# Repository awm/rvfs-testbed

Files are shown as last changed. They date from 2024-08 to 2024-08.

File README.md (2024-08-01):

# RISC-V from Scratch Testbed

This project is ancillary to the primary RISC-V from Scratch (CPU) project and is concerned with the design and
implementation of the debugging, programming, and testing infrastructure for the processor.

## Requirements

*TBD*

## Experiments

The `experiments` subdirectory contains some hardware and firmware designs explore potential features of the testbed
prior to incorporating them into the testbed architecture.  They are presented as-is and will not be updated after the
experiment is concluded.

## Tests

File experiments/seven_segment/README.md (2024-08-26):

# Hexadecimal Seven Segment Chain Experiment

## Hardware Architecture

Using shift registers, two seven-segment displays are chained so that they can all be updated via a low pin count
interface on the RP2040 (transmit-only SPI 1 port).  Each display digit requires an 8-bit shift register (7 segments and
the decimal point), conveniently fitting each into one byte.  The shift registers are linked in a cascaded manner, with
the first data input tied to the SPI 1 TX pin on the microcontroller and the shift register clock driven by the SPI
clock, with the SPI port configured in mode 0 (CPOL = 0, CPHA = 0).  Finally, shift register storage clock is driven by
the SPI chip select line, latching the latest shifted-in values to the display.

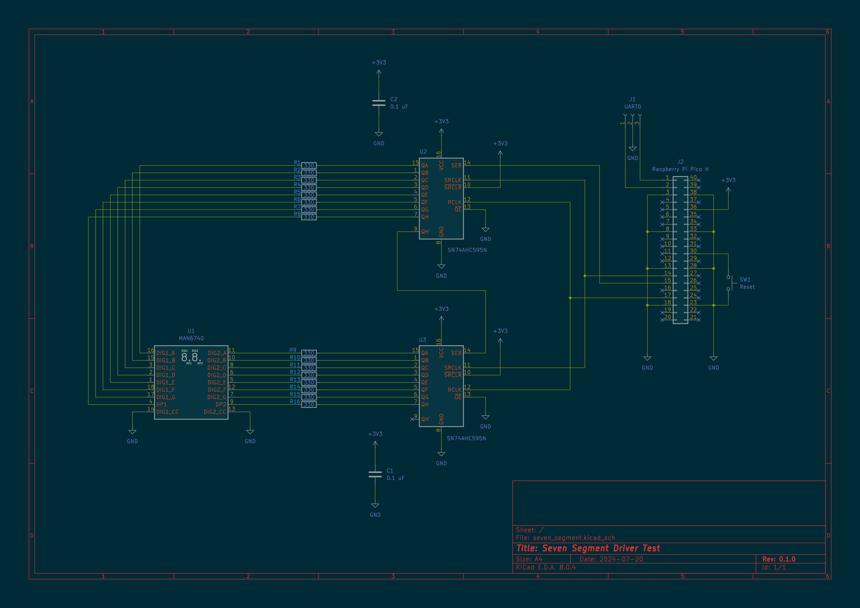
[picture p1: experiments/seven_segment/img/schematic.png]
Schematic


## Firmware Architecture

The pins selected for the interface allow for flexibility in the firmware implementation.  Any of the SPI 1 peripheral,
bit-banged GPIO, or a custom PIO implementation could be used.  The initial experiment uses the dedicated SPI 1
peripheral together with DMA.

The SPI port is initialized for mode 0, with DMA for transmission, and with all receive related errors suppressed.

In this experiment the application passes a byte buffer containing the raw value to be displayed.  Within the display
driver, a lookup table is used to translate the nibbles of each of those bytes to a corresponding single byte bit field
for the display.  Note that the array to be shifted out is big-endian for display purposes, and the farthest display
value in the chain is shifted out first.  Once the bitstream buffer has been constructed, it is passed off to the DMA to
trigger the SPI transmission.

Interpolator 0 is used to calculate the lookup table indices for each nibble of each byte.  This was done primarily to
experiment with the interpolator rather than for any major performance advantage.  The same thing could be achieved in
normal code with a few more cycles and some regular bitwise operations.

## Results

Successfully implemented and demonstrated:

Breadboarded circuit running

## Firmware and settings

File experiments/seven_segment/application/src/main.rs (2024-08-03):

#![doc = include_str!("../../README.md")]
#![no_main]
#![no_std]
#![warn(missing_docs)]

use bsp::{entry, hal, hal::dma::DMAExt, hal::fugit::RateExtU32, hal::Clock, pac};
use embedded_hal::{delay::DelayNs, digital::OutputPin, spi};
use hexchain::{Display, DisplayData};
use panic_halt as _;
use rp_pico as bsp;

mod hexchain;

/// Application entry point.
#[entry]
fn main() -> ! {
    let mut pac = pac::Peripherals::take().unwrap();
    let mut watchdog = hal::Watchdog::new(pac.WATCHDOG);
    let clocks = hal::clocks::init_clocks_and_plls(
        bsp::XOSC_CRYSTAL_FREQ,
        pac.XOSC,
        pac.CLOCKS,
        pac.PLL_SYS,
        pac.PLL_USB,
        &mut pac.RESETS,
        &mut watchdog,
    )
    .ok()
    .unwrap();
    let mut timer = hal::timer::Timer::new(pac.TIMER, &mut pac.RESETS, &clocks);

    let sio = hal::Sio::new(pac.SIO);
    let pins = bsp::Pins::new(
        pac.IO_BANK0,
        pac.PADS_BANK0,
        sio.gpio_bank0,
        &mut pac.RESETS,
    );
    let dma = pac.DMA.split(&mut pac.RESETS);

    // Onboard LED
    let mut led_pin = pins.led.into_push_pull_output();

    // SPI 1 configuration
    let sclk = pins.gpio10.into_function::<hal::gpio::FunctionSpi>();
    let mosi = pins.gpio11.into_function::<hal::gpio::FunctionSpi>();
    let cs = pins.gpio13.into_push_pull_output();
    let spi_pins = (mosi, sclk);
    let spi = hal::spi::Spi::<_, _, _>::new(pac.SPI1, spi_pins).init(
        &mut pac.RESETS,
        clocks.peripheral_clock.freq(),
        64_000_000.Hz(),
        spi::MODE_0,
    );

    let mut display = Display::new(spi, cs, dma.ch0, sio.interp0);

    // Blink all of the decimal points three times on startup
    let mut show = true;
    let mut decimals = [true; hexchain::CHAIN_LENGTH];
    display.set(DisplayData::AllOff);
    for _ in 0..6 {
        led_pin.set_state(show.into()).unwrap();
        display.set(DisplayData::DecimalPoints(&decimals));
        display.show();
        timer.delay_ms(500);

        show = !show;
        decimals.fill(show);
    }
    decimals.fill(false);
    display.set(DisplayData::DecimalPoints(&decimals));
    display.set(DisplayData::AllOn);

    // Start displaying rolling counter
    let mut bytes: [u8; hexchain::DATA_LENGTH] = [0; hexchain::DATA_LENGTH];
    let index = bytes.len() - 1;
    loop {
        led_pin.set_high().unwrap();
        timer.delay_ms(500);
        led_pin.set_low().unwrap();
        timer.delay_ms(500);

        display.set(DisplayData::Values(&bytes));
        display.show();

        bytes[index] = bytes[index].wrapping_add(1);
    }
}

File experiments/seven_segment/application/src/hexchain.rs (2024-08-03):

//! Experimental driver for a sequence of shift register linked seven segment displays.
//!
//! ## Display Segment Organization
//!
//! ```
//!     A
//!    ---
//! F | G | B
//!    ---
//! E |   | C
//!    --- o
//!     D  DP
//! ```
//!

use cortex_m::singleton;
use embedded_hal::{digital::OutputPin, spi::SpiBus};
use rp_pico::hal::{dma, sio, sio::Lane};

/// Maximum display chain length (number of hex digits).
pub const CHAIN_LENGTH: usize = u32::BITS as usize;
/// Maximum size of buffer that can be displayed (each nibble corresponds to one display digit).
pub const DATA_LENGTH: usize = CHAIN_LENGTH / 2;

/// Bit corresponding to display segment "A."
const SEG_A: u8 = 1 << 0;
/// Bit corresponding to display segment "B."
const SEG_B: u8 = 1 << 1;
/// Bit corresponding to display segment "C."
const SEG_C: u8 = 1 << 2;
/// Bit corresponding to display segment "D."
const SEG_D: u8 = 1 << 3;
/// Bit corresponding to display segment "E."
const SEG_E: u8 = 1 << 4;
/// Bit corresponding to display segment "F."
const SEG_F: u8 = 1 << 5;
/// Bit corresponding to display segment "G."
const SEG_G: u8 = 1 << 6;
/// Bit corresponding to decimal point.
const SEG_DP: u8 = 1 << 7;

/// Lookup table constructing each hexadecimal character using the most appropriate display segments.
const CHAR_TABLE: [u8; 16] = [
    !(SEG_G | SEG_DP),                 // 0x0
    SEG_B | SEG_C,                     // 0x1
    !(SEG_C | SEG_F | SEG_DP),         // 0x2
    !(SEG_E | SEG_F | SEG_DP),         // 0x3
    !(SEG_A | SEG_D | SEG_E | SEG_DP), // 0x4
    !(SEG_B | SEG_E | SEG_DP),         // 0x5
    !(SEG_B | SEG_DP),                 // 0x6
    SEG_A | SEG_B | SEG_C,             // 0x7
    !SEG_DP,                           // 0x8
    !(SEG_E | SEG_DP),                 // 0x9
    !(SEG_D | SEG_DP),                 // 0xA
    !(SEG_A | SEG_B | SEG_DP),         // 0xb
    SEG_A | SEG_F | SEG_E | SEG_D,     // 0xC
    !(SEG_A | SEG_F | SEG_DP),         // 0xd
    !(SEG_B | SEG_C | SEG_DP),         // 0xE
    !(SEG_B | SEG_C | SEG_D | SEG_DP), // 0xF
];

/// RP2040 interpolator wrapper which configures and runs it as a character lookup table index generator.
pub trait Interp {
    /// Configure interpolator for lookup index generation.
    fn init(&mut self);
    /// Generate a pair of (high nibble, low nibble) character lookup table indices for the given byte of data.
    fn run(&mut self, data: u8) -> (usize, usize);
}

/// Interpolator handling of lookup generation for each interpolator instance.
macro_rules! interpolators {
    ( $($interp:ident),+ ) => {
            $(
                impl Interp for sio::$interp {
                    fn init(&mut self) {
                        self.get_lane0().set_base(0);
                        self.get_lane1().set_base(0);

                        let mut lanectrl = sio::LaneCtrl::new();
                        lanectrl.mask_msb = 3;
                        self.get_lane0().set_ctrl(lanectrl.encode());

                        lanectrl.cross_input = true;
                        lanectrl.shift = 4;
                        self.get_lane1().set_ctrl(lanectrl.encode());
                    }
                    fn run(&mut self, data: u8) -> (usize, usize) {
                        self.get_lane0().set_accum(data as u32);
                        let lo = self.get_lane0().peek() as usize;
                        let hi = self.get_lane1().peek() as usize;
                        (hi, lo)
                    }
                }
            )+
        };
}

interpolators!(Interp0, Interp1);

/// Data which modifies the display state.
#[allow(dead_code)]
pub enum DisplayData<'a> {
    /// Turn on all digits (decimal points are unaffected).
    AllOn,
    /// Turn off (blank) all digits (decimal points are unaffected).
    AllOff,
    /// Turn on those digits which are marked `true`, blank all others (decimal points are unaffected).
    On(&'a [bool; CHAIN_LENGTH]),
    /// Set the decimal point for all digits which are marked `true`, clear it for all others.
    DecimalPoints(&'a [bool; CHAIN_LENGTH]),
    /// Provide the data to display for all digits.
    Values(&'a [u8; DATA_LENGTH]),
}

/// Display chain controller.
pub struct Display<S, C, D, I>
where
    S: dma::WriteTarget<TransmittedWord = u8> + SpiBus,
    C: OutputPin,
    D: dma::SingleChannel,
    I: Interp,
{
    /// SPI port from which to shift data.
    spi: Option<S>,
    /// Chip select line for SPI port.
    cs: C,
    /// DMA channel to use for bitstream transmission.
    dma: Option<D>,
    /// Interpolator to use for character lookup index generation.
    interp: I,

    /// On state of each display chain member.
    on: [bool; CHAIN_LENGTH],
    /// Decimal point state of each display chain member.
    points: [u8; CHAIN_LENGTH],
    /// Data to be displayed as hexadecimal.
    data: [u8; DATA_LENGTH],
    /// Bitstream to be shifted out to the display members.
    bits: Option<&'static mut [u8; CHAIN_LENGTH]>,
}
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

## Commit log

2024-08-01 feat: Create experimental display driver
    [seven_segment.kicad_pcb, seven_segment.kicad_sch]
2024-08-03 feat: Finish seven segment experiment
    Create prototype driver for chained seven segment displays paired with shift registers.
    [seven_segment.kicad_sch]
